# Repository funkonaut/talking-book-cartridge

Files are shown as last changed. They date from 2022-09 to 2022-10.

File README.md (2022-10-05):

# Talking Book and Joy Player Cartridge
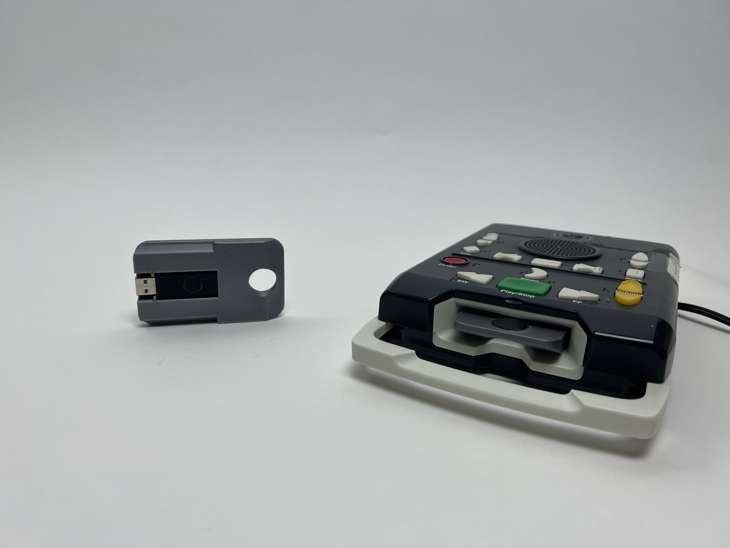
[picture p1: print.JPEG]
3D print of the cartridge with flash drive inserted


 Customizable model for usb swappable [talking book and joy player cartridges](https://www.aph.org/product/digital-talking-book-cartridge/)

## Features
- Works with [generic flashdrives](https://www.amazon.com/Kootion-Flash-Drive-Memory-Colors/dp/B016I79NPG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)
- Fully parametric and editable OpenSCAD script allows you to use any flash drive that will fit!
- Cost around $.50 to print and with cheap flash drives brings the total price to ~$1! 
- Print in any color
- Swappable storage and customizable

## Why?
While the Joy Player does have a usb port in the back, not every student is able to plug in flash drives correctly. The cartridge enables student's independnece but cost $14 and is not availble for purchase with quota funds. Our schools librarian was sick of spending $14 on each lost cartridge as students go through them and wanted a cost effective alternative. This model provides not only a cost effective solution but also an improvement on the original cartridge design. USB drives can be swapped for more or less storage, no need for a male to female usb cable to load cartridges, simply remove the usb drive and plug into the computer like any other flash storage. Also the OpenSCAD code is fully customizable and open source so one can add text, braille, or other tactile markers to the cartridge!

## Print Settings
.15 layer height, 15% infill, with supports and normal PLA settings provide great results takes ~2 hours to print and uses ~22g of filament (~$.60)

## To Do
- Longivity test with students
- Add tactile marker options 
- Add text or braille options (braille on sides of cartridge?)

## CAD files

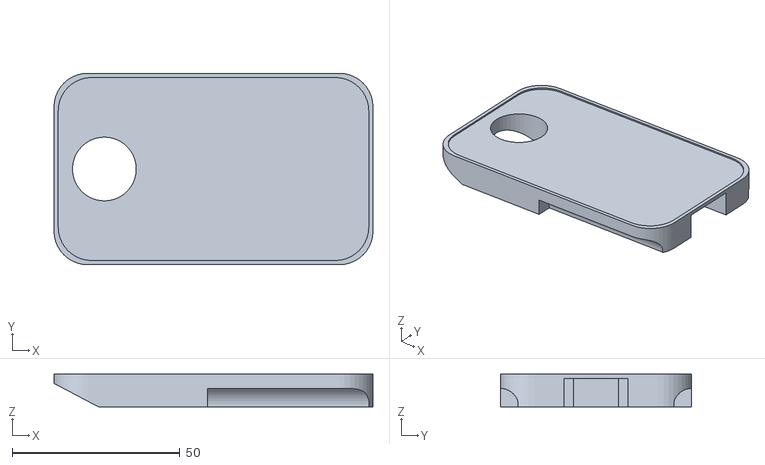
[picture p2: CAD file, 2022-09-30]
cartridge_v2.stl
95.0 x 57.0 x 9.75

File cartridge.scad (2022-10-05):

//Author: Chris Correll
//Date: 9/5/2022
//Description: Joy Player replacement cartridge for easy flash drive swabbing

include <MCAD/3d_triangle.scad>

$fn = 40;
e=.01;

//cartridge
x = 95;
y = 57;
z = 9.75;
hole_r = 19/2;
hole_off = 5.5; //5.25 changed
hole_h = z+e;
lip_off_x = 2.5;
lip_off_y = 2.5;
lip_off_z = .5;//from .5 ~ also text thickness
msg = "Rock"; //limit to 10 chars?
txt_off = 30;

//guide slots
slot_length = 48; 
slot_r = 5.5;

//cut out for flash drive
cut_x = 50.5;
cut_y = 19;
cut_z = 8.5;  //from 8.75 
cut_hole_r = 9.5/2;
cut_hole_h = 8.75;
cut_hole_off = 15.25; 
//cut_off_x =
//cut_off_y
//cut_off_z = 1; //3.3 from top of cartridge to flash drive 2 from case outer to flash drive and 2.5 from cut out to top of cartridge so 4.5-3.3 offset need
drive_off_x = 12;
drive_off_y = 3.5;
drive_off_thick = 2;

module right_triangle(a,b,h){
    linear_extrude(h){
    polygon(points = [ [a, 0], [0,b], [a,b]],  convexity = 1);
}
}

module rounded_cube(w,l,z,rad1,rad2){
    hull(){
        translate([(w)/2-rad1,(l)/2-rad1,0])
        cylinder(h = z, r = rad1, center = true);
        translate([-((w)/2-rad2),-((l)/2-rad2),0])
        cylinder(h = z, r = rad2, center = true);
        translate([-((w)/2-rad1),(l)/2-rad1,0])
        cylinder(h = z, r = rad1, center = true);
        translate([(w)/2-rad2,-((l)/2-rad2),0])
        cylinder(h = z, r = rad2, center = true);  
    };
}

module gen_text(msg,x_bbox, y_bbox, thickness){
 num_letters = len(msg);
 size = x_bbox/num_letters;
linear_extrude(thickness){
 text(msg,size,halign="center",valign="top");
}
}

union(){
//Text 
translate([-x/2+txt_off,0,z/2])
rotate([0,0,90])
gen_text(msg,y,x/4,lip_off_z);

//stops for flash drive
translate([x/2+drive_off_thick/2-drive_off_x,drive_off_x-drive_off_y,-lip_off_z/2])
cube([drive_off_thick, drive_off_y, z-lip_off_z],center=true);
translate([x/2+drive_off_thick/2-drive_off_x,-drive_off_x+drive_off_y,-lip_off_z/2])
cube([drive_off_thick, drive_off_y, z-lip_off_z],center=true);

//cartridge
difference(){
//main cartridge with ridge
rounded_cube(x,y,z,10,10);
translate([0,0,z-lip_off_z])
rounded_cube(x-lip_off_x,y-lip_off_y,z,10,10);

union(){
//holder hole
translate([-x/2+hole_r+hole_off,0,0])
cylinder(r = hole_r, h = hole_h, center=true);

//flash drive slot
translate([x/2-cut_x/2,0,-z/2+cut_z/2])
cube([cut_x,cut_y,cut_z],center=true);

//hole change cut_z to 7.5 
//translate([cut_hole_off,0,-z/2+cut_hole_h/2])
//#cylinder(r = cut_hole_r, h = cut_hole_h, center=true);

//guide slots
translate([x/2-cut_x/2,-y/2,-z/2])
rotate([0,90,0])
cylinder(r=slot_r,h=slot_length,center=true);
translate([x/2-cut_x/2,y/2,-z/2])
rotate([0,90,0])
cylinder(r=slot_r,h=slot_length,center=true);
}

//angeled back
b = 13.25;
a = 7;
translate([b-x/2,-y/2,a-z/2])
//translate([b/2,-y/2,z/2-a/2])
rotate([90,90,180])
right_triangle(a,b,y);
}
}

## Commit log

2022-09-07 Adds code for v1
    [cartridge.scad, cartridge_v1.stl]
2022-09-30 adds angeled back and shift hole back
    [cartridge.scad, cartridge_v2.stl]
2022-10-05 add text customization to model and update read me with printing directions
    [cartridge.scad]
